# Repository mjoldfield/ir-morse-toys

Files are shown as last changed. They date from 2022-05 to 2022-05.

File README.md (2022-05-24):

# Games with Morse Code at 940nm

This repository contains designs for two detectors and two transmitters
for Morse Code signals, all working with 940nm infra-red light.

You can read more on [my website](https://mjoldfield.com/atelier/2022/01/ir-fun.html).

If you’re near Cambridge, UK you might enjoy the [geocache](https://www.geocaching.com/geocache/GC86BQY_to-the-birdhouse)
 for which they were designed.

## Building the firmware

There are three steps:

  1. Install a GNU toolchain. You can download this from
	 [ARM](https://developer.arm.com/Tools%20and%20Software/GNU%20Toolchain),
	 but it is often available as system package in e.g. Debian.

  1. Install [libopencm3](https://libopencm3.org):

		$ git submodule init
		
		$ git submodule upgrade

		$ make -C libopencm3

  1. Compile the firmware

		$ make -C tx-bluepill/firmware

		$ make -C tx-stm32l431/firmware

The libopencm3-rules.mk file contains a number of fake targets to flash the firmware.

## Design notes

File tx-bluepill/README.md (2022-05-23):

# A Bluepill STM32F103 based emitter



You can read more on [my website](https://mjoldfield.com/atelier/2022/01/ir-emitter-bp.html).

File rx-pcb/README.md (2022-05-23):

# A PCB based Detector



You can read more on [my website](https://mjoldfield.com/atelier/2022/01/rx-pcb.html).

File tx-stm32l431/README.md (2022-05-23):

# A STM32L431 based emitter



You can read more on [my website](https://mjoldfield.com/atelier/2022/01/ir-emitter-bb.html).

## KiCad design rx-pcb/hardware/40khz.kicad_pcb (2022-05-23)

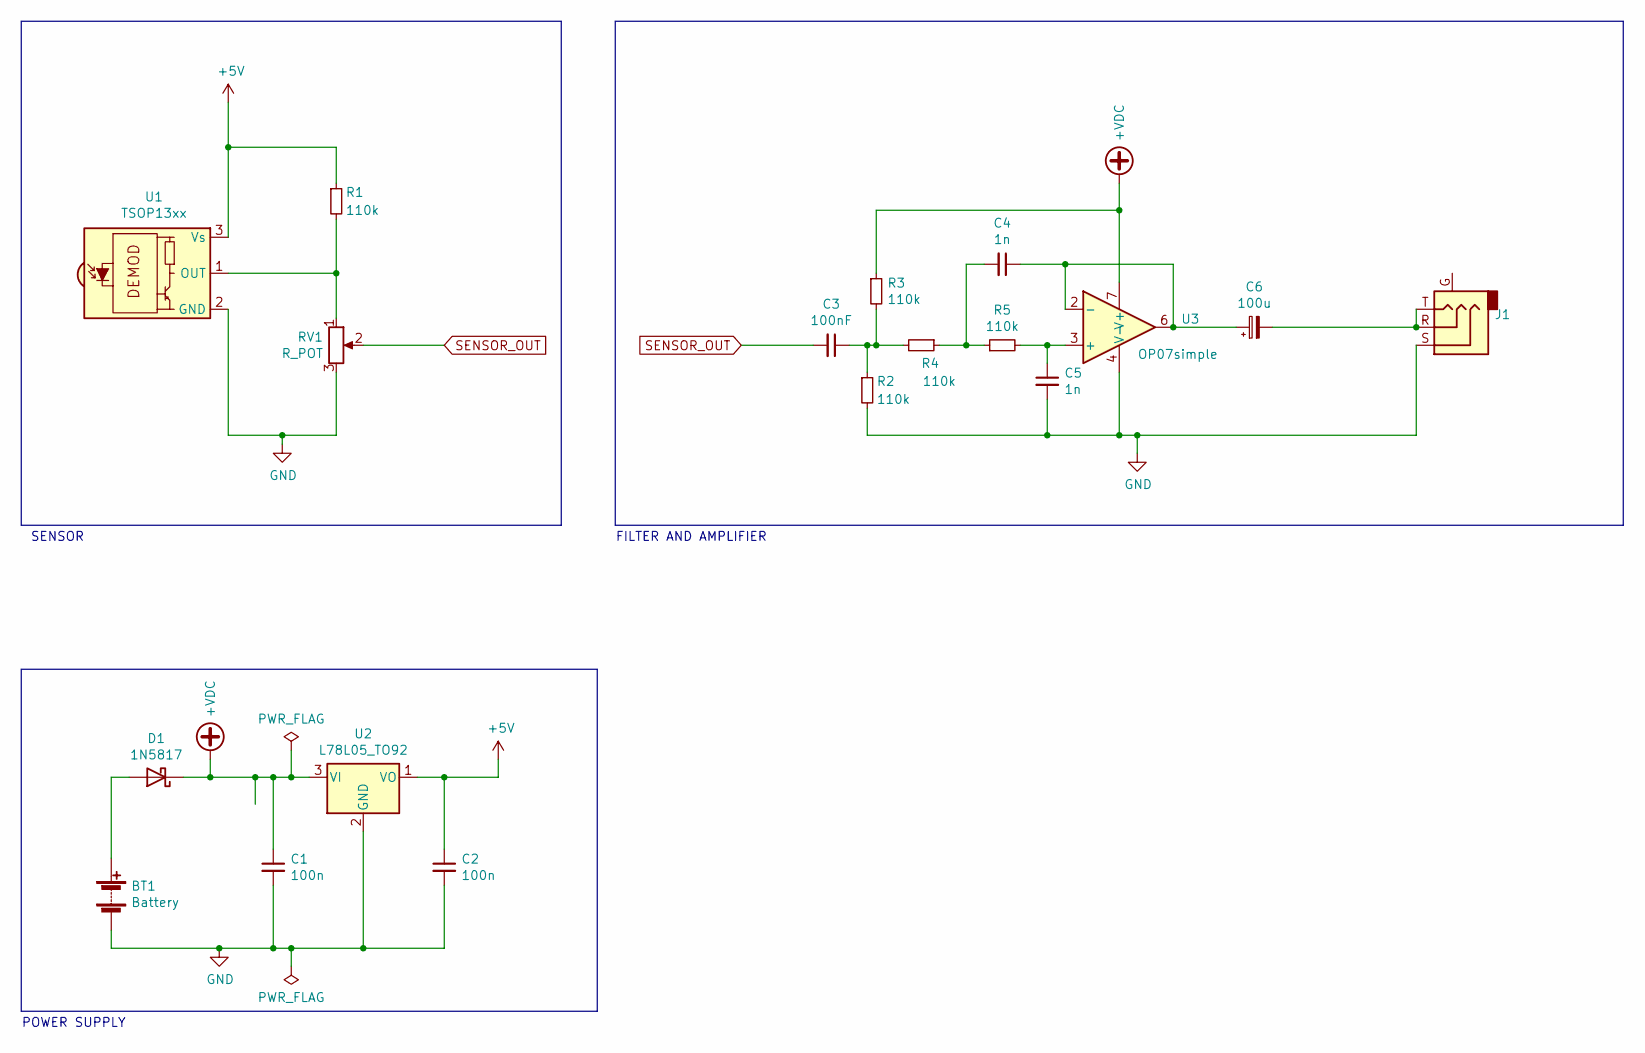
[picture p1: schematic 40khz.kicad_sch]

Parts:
BT1: Battery; Battery_Keystone_968
C1, C2: 100n; C_Disc_D10.0mm_W2.5mm_P5.00mm
C3: 100nF; C_Disc_D10.0mm_W2.5mm_P5.00mm
C4, C5: 1n; C_Rect_L10.0mm_W5.0mm_P5.00mm_P7.50mm
C6: 100u; CP_Radial_D6.3mm_P2.50mm
D1: 1N5817; D_DO-41_SOD81_P10.16mm_Horizontal
J1: AudioJack3_Ground; TruConnect_3.5mm_StereoSocket
R1, R2, R3, R4, R5: 110k; R_Axial_DIN0207_L6.3mm_D2.5mm_P10.16mm_Horizontal
RV1: R_POT; Potentiometer_Piher_PC-16_Single_Horizontal
U1: TSOP13xx; Vishay_MINIMOLD-3Pin
U2: L78L05_TO92; TO-92_Inline
U3: OP07simple; DIP-8_W7.62mm_Socket

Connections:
+5V: C2.1, R1.1, U1.3 (Vs), U2.1 (VO)
+VDC: C1.1, D1.1 (K), R3.1, U2.3 (VI), U3.7 (V+)
GND: BT1.2 (-), C1.2, C2.2, C5.2, J1.S, R2.2, RV1.3, U1.2 (GND), U2.2 (GND), U3.4 (V-)
unnamed: BT1.1 (+), D1.2 (A)
unnamed: C3.1, R2.1, R3.2, R4.2
unnamed: C4.1, C6.1, U3.2 (-), U3.6
unnamed: C4.2, R4.1, R5.1
unnamed: C5.1, R5.2, U3.3 (+)
unnamed: C6.2, J1.R, J1.T
unnamed: R1.2, RV1.1, U1.1 (OUT)
SENSOR_OUT: C3.2, RV1.2

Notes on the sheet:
SENSOR
POWER SUPPLY
FILTER AND AMPLIFIER

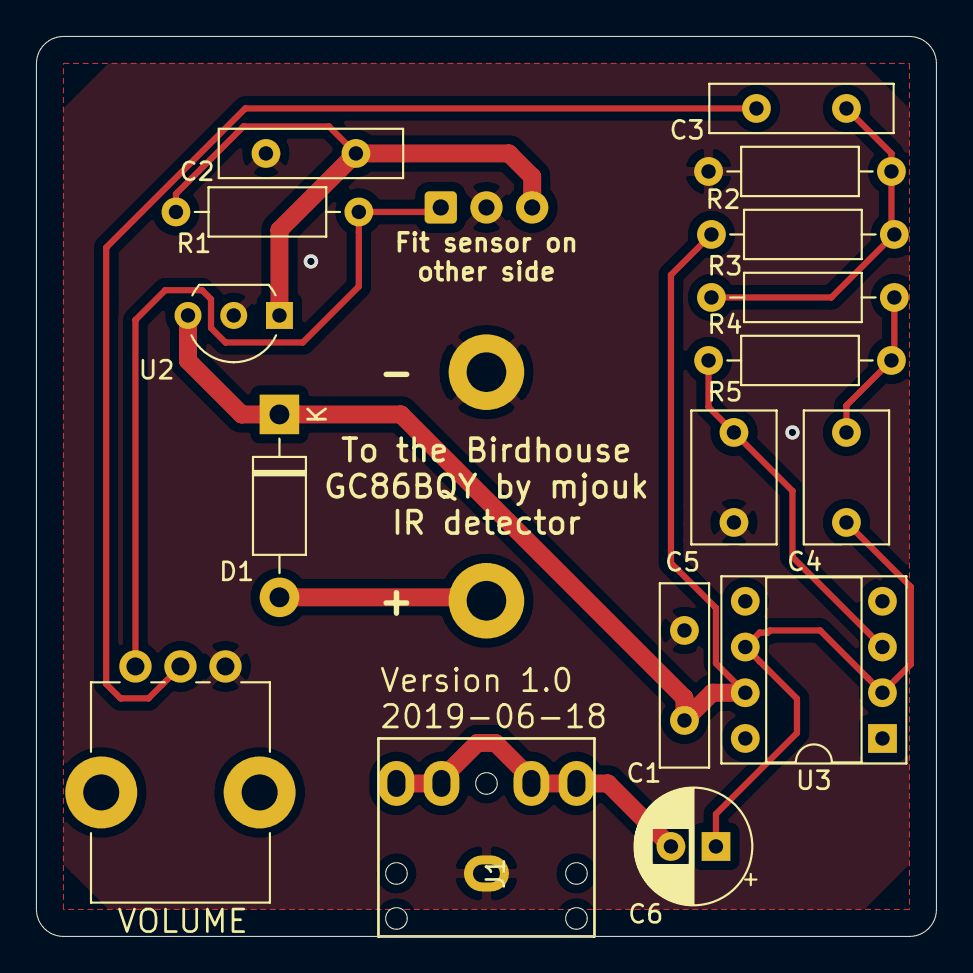
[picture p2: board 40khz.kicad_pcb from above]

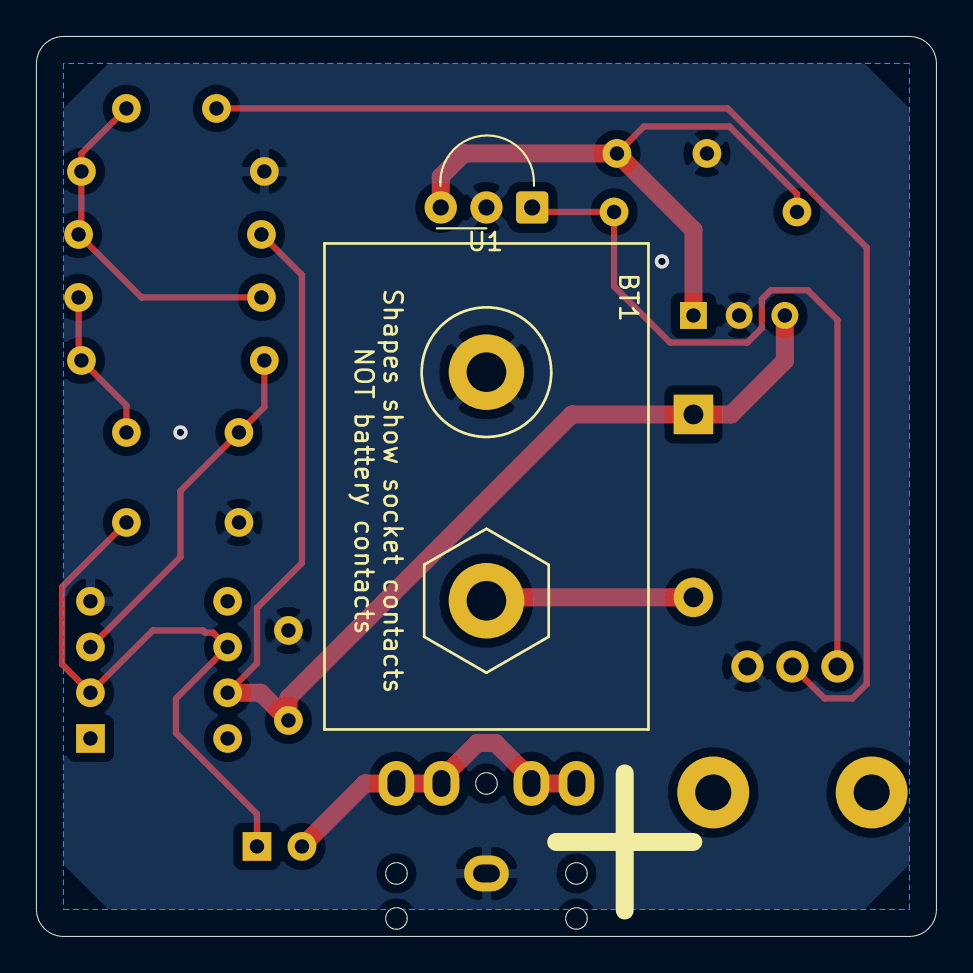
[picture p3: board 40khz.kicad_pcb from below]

Board: 2 copper layers, 50.0 x 50.0 mm, 18 parts (2 on the bottom side), 11 nets.

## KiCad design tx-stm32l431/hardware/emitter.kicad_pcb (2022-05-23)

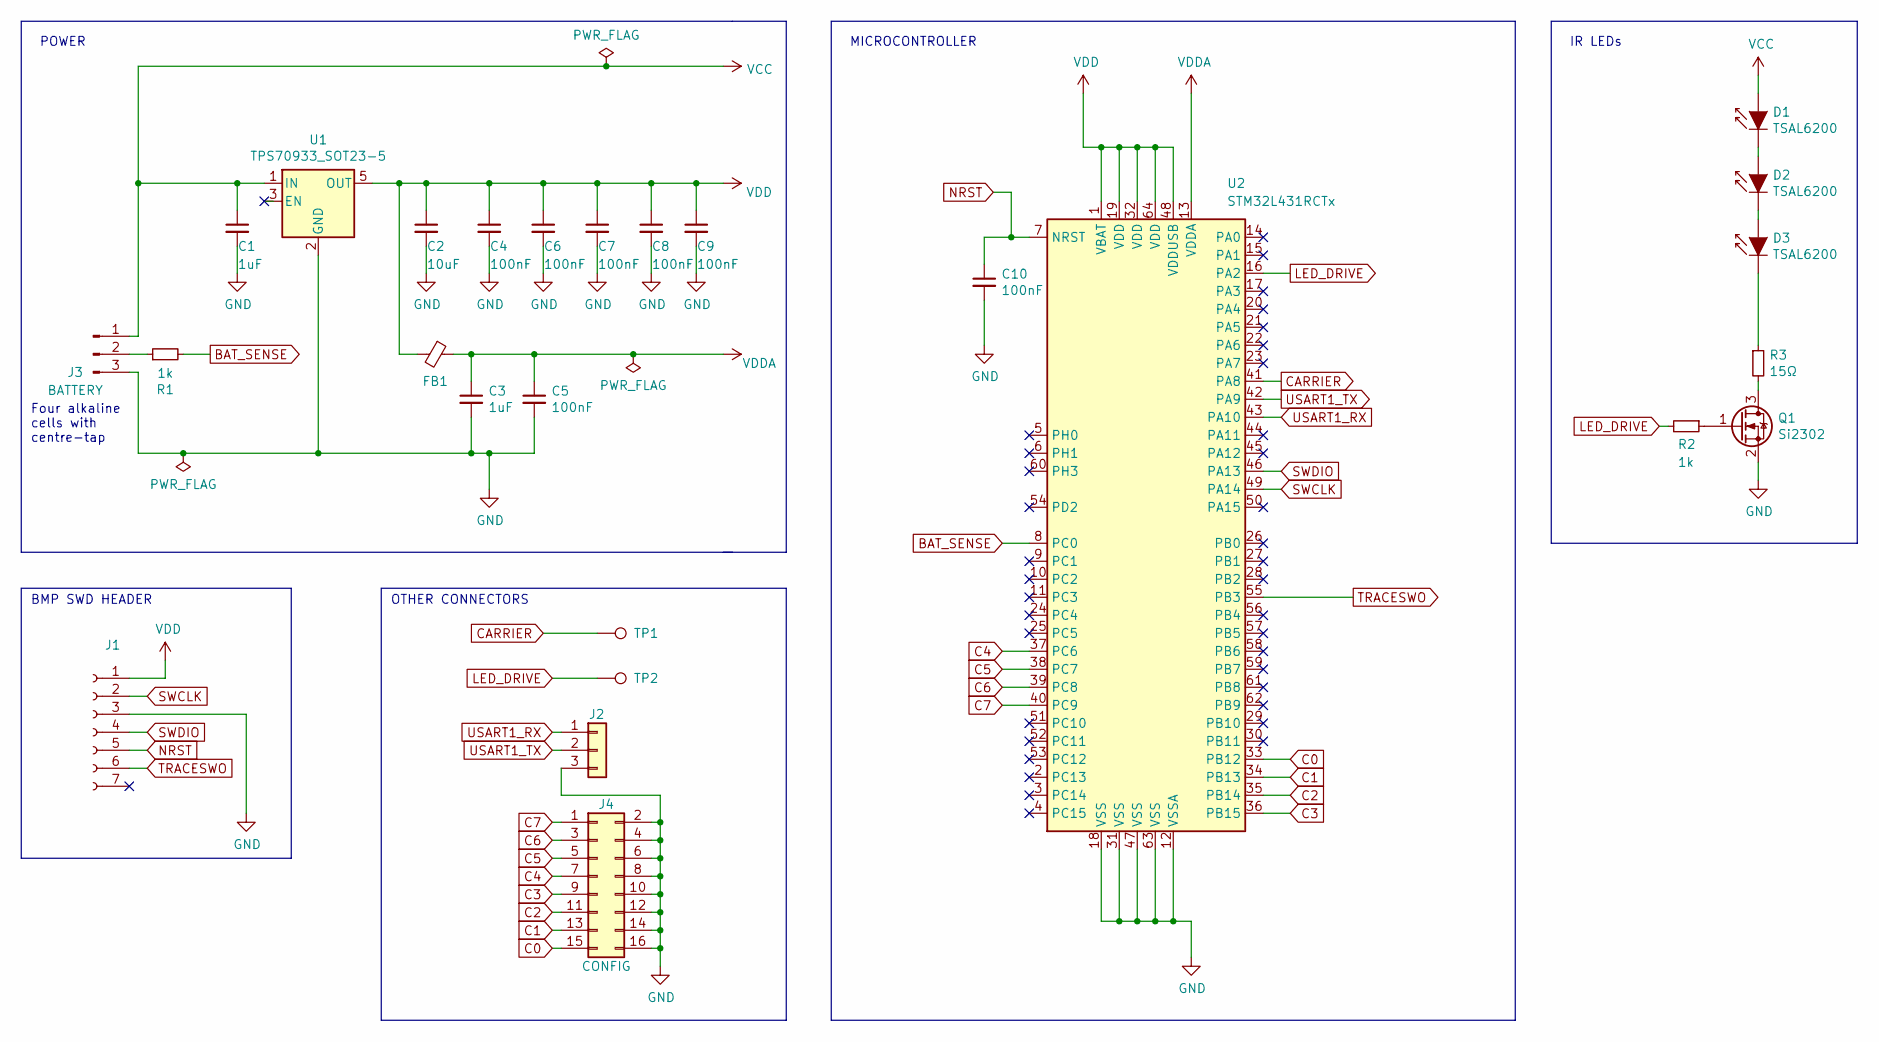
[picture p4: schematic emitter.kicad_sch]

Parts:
C1, C3: 1uF; C_0603_1608Metric_Pad1.05x0.95mm_HandSolder
C2: 10uF; C_0603_1608Metric_Pad1.05x0.95mm_HandSolder
C4, C5, C6, C7, C8, C9, C10: 100nF; C_0603_1608Metric_Pad1.05x0.95mm_HandSolder
D1, D2, D3: TSAL6200; LED_D5.0mm_Horizontal_O1.27mm_Z3.0mm_IRBlack
FB1: Ferrite_Bead_Small; L_0603_1608Metric_Pad1.05x0.95mm_HandSolder
J1: Conn_01x07_Female; PinSocket_1x07_P2.54mm_Vertical
J2: Conn_01x03; PinSocket_1x03_P2.54mm_Vertical
J3: BATTERY; PinHeader_1x03_P2.54mm_Vertical
J4: CONFIG; PinHeader_2x08_P2.54mm_Vertical
Q1: Si2302; SOT-23
R1, R2: 1k; R_0603_1608Metric_Pad1.05x0.95mm_HandSolder
R3: 15Ω; R_0603_1608Metric_Pad1.05x0.95mm_HandSolder
TP1, TP2: TestPoint; TestPoint_Loop_D2.60mm_Drill1.4mm_Beaded
U1: TPS70933_SOT23-5; SOT-23-5
U2: STM32L431RCTx; LQFP-64_10x10mm_P0.5mm

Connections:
BAT_SENSE: R1.2, U2.8 (PC0)
C0: J4.15, U2.33 (PB12)
C1: J4.13, U2.34 (PB13)
C2: J4.11, U2.35 (PB14)
C3: J4.9, U2.36 (PB15)
C4: J4.7, U2.37 (PC6)
C5: J4.5, U2.38 (PC7)
C6: J4.3, U2.39 (PC8)
C7: J4.1, U2.40 (PC9)
CARRIER: TP1.1, U2.41 (PA8)
GND: C1.2, C2.2, C3.2, C4.2, C5.2, C6.2, C7.2, C8.2, C9.2, C10.2, J1.3, J2.3, J3.3, J4.2, J4.4, J4.6, J4.8, J4.10, J4.12, J4.14, J4.16, Q1.2 (S), U1.2 (GND), U2.12 (VSSA), U2.18 (VSS), U2.31 (VSS), U2.47 (VSS), U2.63 (VSS)
LED_DRIVE: R2.2, TP2.1, U2.16 (PA2)
NRST: C10.1, J1.5, U2.7 (NRST)
unnamed: D1.1 (K), D2.2 (A)
unnamed: D2.1 (K), D3.2 (A)
unnamed: D3.1 (K), R3.1
unnamed: J3.2, R1.1
unnamed: Q1.1 (G), R2.1
unnamed: Q1.3 (D), R3.2
SWCLK: J1.2, U2.49 (PA14)
SWDIO: J1.4, U2.46 (PA13)
TRACESWO: J1.6, U2.55 (PB3)
USART1_RX: J2.1, U2.43 (PA10)
USART1_TX: J2.2, U2.42 (PA9)
VCC: C1.1, D1.2 (A), J3.1, U1.1 (IN)
VDD: C2.1, C4.1, C6.1, C7.1, C8.1, C9.1, FB1.2, J1.1, U1.5 (OUT), U2.1 (VBAT), U2.19 (VDD), U2.32 (VDD), U2.48 (VDDUSB), U2.64 (VDD)
VDDA: C3.1, C5.1, FB1.1, U2.13 (VDDA)

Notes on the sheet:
BMP SWD HEADER
IR LEDs
MICROCONTROLLER
OTHER CONNECTORS
POWER
Four alkaline cells with centre-tap

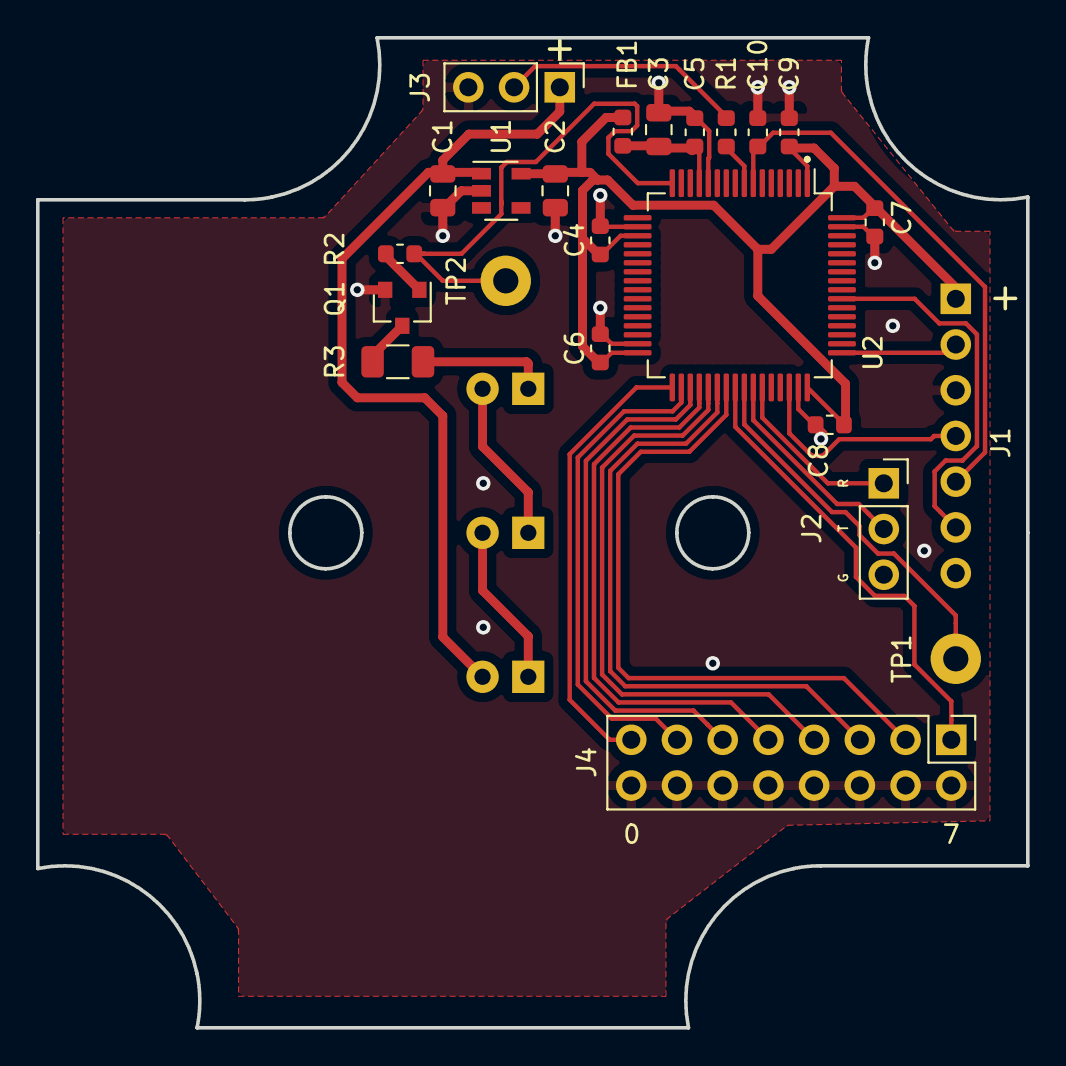
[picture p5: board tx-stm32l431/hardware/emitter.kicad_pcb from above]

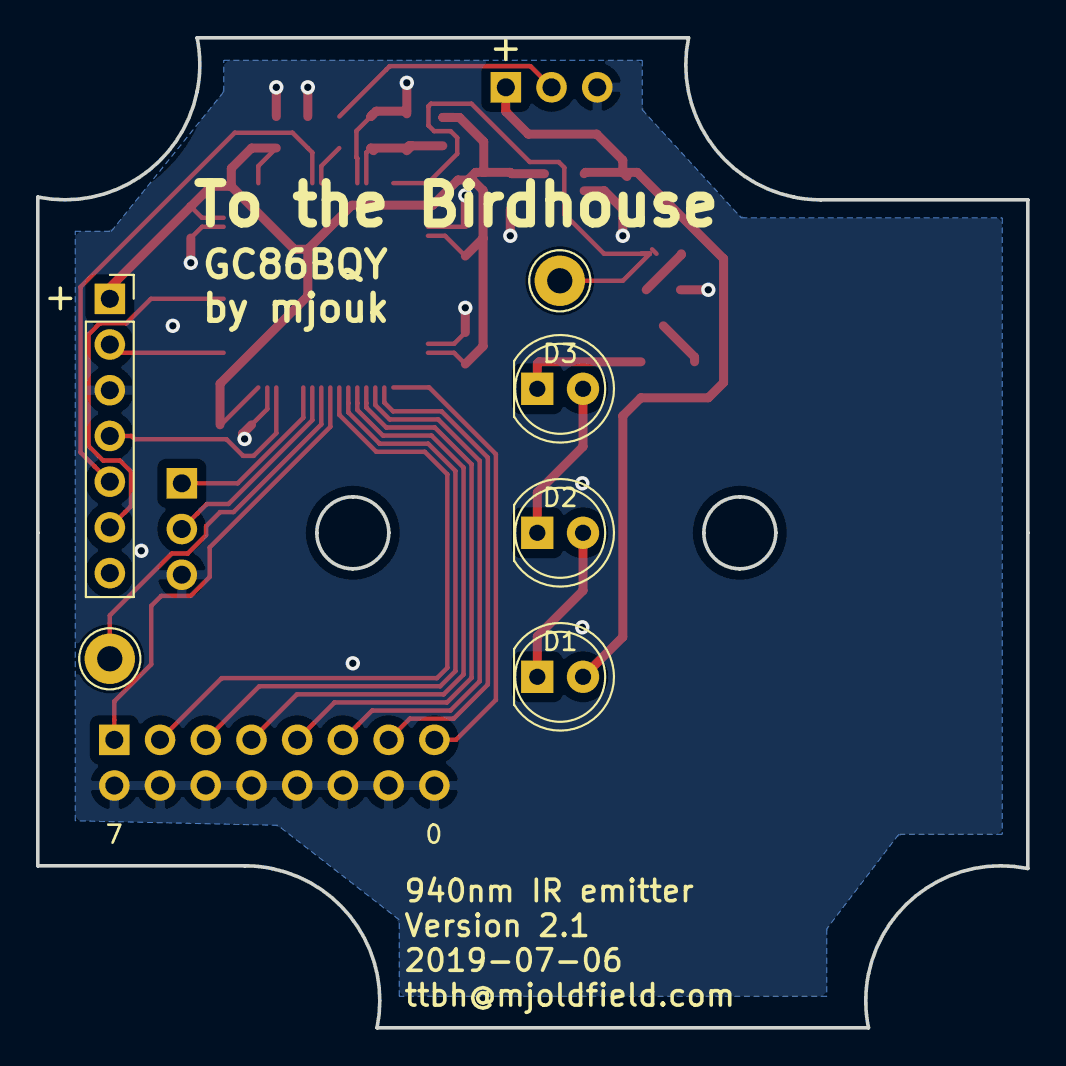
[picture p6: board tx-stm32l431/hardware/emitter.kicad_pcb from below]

Board: 2 copper layers, 55.0 x 55.0 mm, 26 parts (6 on the bottom side), 27 nets.

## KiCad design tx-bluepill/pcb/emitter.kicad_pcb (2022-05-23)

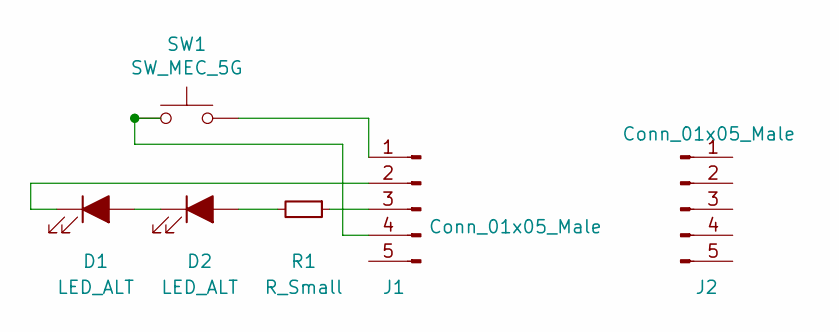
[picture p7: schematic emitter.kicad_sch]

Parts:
D1, D2: LED_ALT; LED_D5.0mm
J1, J2: Conn_01x05_Male; PinHeader_1x05_P2.54mm_Vertical
R1: R_Small; R_Axial_DIN0204_L3.6mm_D1.6mm_P5.08mm_Horizontal
SW1: SW_MEC_5G; SW_TH_Tactile_Omron_B3F-10xx

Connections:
unnamed: D1.1 (K), J1.2
unnamed: D1.2 (A), D2.1 (K)
unnamed: D2.2 (A), R1.2
unnamed: J1.1, SW1.3 (B), SW1.4 (B)
unnamed: J1.3, R1.1
unnamed: J1.4, SW1.1 (A), SW1.2 (A)

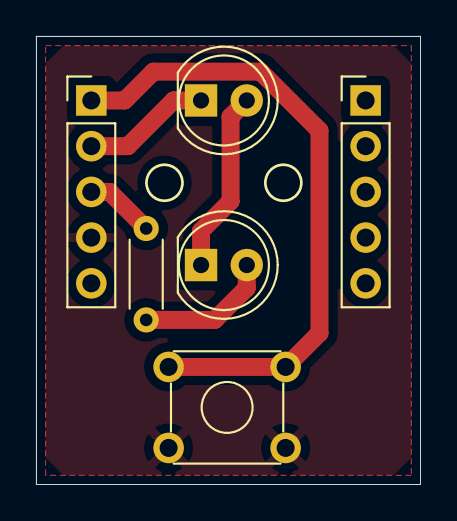
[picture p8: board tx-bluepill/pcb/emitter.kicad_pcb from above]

Board: 2 copper layers, 21.3 x 24.9 mm, 6 parts (0 on the bottom side), 6 nets.

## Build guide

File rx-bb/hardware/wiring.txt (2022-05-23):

Wire links

W1  J30  -
W2  H28 H25
W3  E2  F2

U1  A2 A3 A4

U2  F21 to E18

R1  C4   +

R2  B2  B4
R3  I12  -
R4  F12  +
R5  G12 G19

D1  D3  D4

C1  F4  H12

C2  B19 F25

VR1 J2 J4 J6

J1  F28 G28 H30 I28 J28

W4  E3  -
W5  F6  -
W6  G18 -
W7  D20 +
W8  F20 D19

B1

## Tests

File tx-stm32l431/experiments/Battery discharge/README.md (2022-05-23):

# Battery discharging

This directory contains data which shows how the battery
discharges when running the emitter when the duty-cycle
of the LED is increased as the battery voltage drops.

## Key results

  - On full-power AAA cells last about 10 hours;

  - D cells last about 12 times as long as AAA cells;

  - Running at 30% of power quadruples the lifetime.

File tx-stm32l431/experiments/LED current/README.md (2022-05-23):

# LED characterization

Currrent/Voltage plots for three and four LEDs in series.

The four LED string is more efficient at higher voltages but there's
not enough current when the batteries run down.  So, use three LEDs
and accept the wasted power at high voltages.

For an applied voltage in the range 4.0--6.5V (which covers the range
the battery will supply) the current is accurately modelled by:

	(I / mA) = 55.86 (V / V) - 200.58

Equivalently,

	(V / V) = 17.9 (I / A) + 3.59

Given that the current limiting resistor had a value of 15Ω this
suggests that the LED behaves as a voltage drop of 1.2V in series with
a 1Ω resistor.

# Model generation

The short Haskell program mkModel.hs generates C source and header files
to embed this model in firmware.

test.c is a simple program to test the model.

You can build them thus:

	stack runghc main.hs

	gcc -Wall -std=c99 -pedantic test.c ledcurve.c -o test

	./test

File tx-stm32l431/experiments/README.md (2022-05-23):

# Empirical tests

These directories contain the results of experiments
which characterized the performance of the emitter.
Documentation is poor.

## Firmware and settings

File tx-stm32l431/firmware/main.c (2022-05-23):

/* ex https://github.com/libopencm3/libopencm3-miniblink/blob/master/template_stm32.c */

#include <stddef.h>

#include <libopencm3/stm32/rcc.h>
#include <libopencm3/stm32/timer.h>
#include <libopencm3/stm32/gpio.h>
#include <libopencm3/stm32/adc.h>
#include <libopencm3/cm3/nvic.h>
#include <libopencm3/stm32/pwr.h>
#include <libopencm3/stm32/iwdg.h>
#include <libopencm3/stm32/flash.h>

#include "morseout.h"
#include "ledcurve.h"

typedef enum _gpio_pin_kind { GPIO_in, GPIO_out, GPIO_alt } gpio_pin_kind;

static const uint8_t gpio_out_set_hi  = 1;
static const uint8_t gpio_out_set_lo  = 2;

typedef struct _GPIOPin {
  uint16_t      pin;
  uint32_t      port;
  gpio_pin_kind kind;
  uint8_t       extra;
} GPIOPin;

// System clock
// 200kHz - 55.8uA, 400kHz - 68.5uA
static const uint32_t master_clk = RCC_CR_MSIRANGE_800KHZ;
static const uint32_t master_f   = 800000L; 

// carr   - 40kHz IR carrier clock
static const uint32_t              carr_freq       = 40000;
static const uint32_t              carr_timer      = TIM15;
static const uint32_t              carr_prescale   = 1;
static const uint32_t              carr_period     = master_f / (carr_freq * carr_prescale);


static const GPIOPin               leds_out = { GPIO2, GPIOA, GPIO_alt, GPIO_AF14 };

// tone_  - 800Hz Morse tone clock
static const uint32_t              tone_freq      = 800;
static const uint32_t              tone_timer     = TIM1;
static const uint32_t              tone_prescale  = 1;
static const uint32_t              tone_period    = master_f / (tone_freq * tone_prescale);

static const GPIOPin               carr_out = { GPIO8, GPIOA, GPIO_alt, GPIO_AF0 };   // MCO

// number of pulses in each burst of carrier, which lasts half the
// period of the tone
static const uint32_t              carr_pulses    = (carr_freq / tone_freq) >> 1;
// select the right master timer to get our trigger from
static const uint8_t               carr_trig_src  = TIM_SMCR_TS_ITR0;

//
// data - call after each symbol so 1,3,7,..  dit times
// 
// NB if this changes from TIM2 then references in the code below
// will have to be changed to match.
//
static const uint32_t              dit_time_ms    = 50;
static const uint32_t              data_timer     = TIM2;
static const uint32_t              data_prescale  = 5000;
static const uint32_t              data_period    = master_f * dit_time_ms /  (1000L * data_prescale);

// ADC for battery sense
static const uint32_t adc_batt      = ADC1;
static const uint32_t adc_batt_port = GPIOC;
static const uint16_t adc_batt_pin  = GPIO0;

static uint32_t v_batt = 0;

// Configuration data: read on boot, then fixed.
static uint32_t config = 0xffffffffL;
// LED power curve
static uint32_t led_curve_id = 0;

static const GPIOPin dbug_int      = { GPIO9, GPIOA, GPIO_out, gpio_out_set_lo };

// Config bits: read them, then set to output and drive LOW
// note the order is MSB first
static const GPIOPin configGPIOs[] = {
				         { GPIO9,   GPIOC, GPIO_in, GPIO_PUPD_PULLUP }
				       , { GPIO8,   GPIOC, GPIO_in, GPIO_PUPD_PULLUP }
				       , { GPIO7,   GPIOC, GPIO_in, GPIO_PUPD_PULLUP }
				       , { GPIO6,   GPIOC, GPIO_in, GPIO_PUPD_PULLUP }
				       , { GPIO15,  GPIOB, GPIO_in, GPIO_PUPD_PULLUP }
				       , { GPIO14,  GPIOB, GPIO_in, GPIO_PUPD_PULLUP }
				       , { GPIO13,  GPIOB, GPIO_in, GPIO_PUPD_PULLUP }
				       , { GPIO12,  GPIOB, GPIO_in, GPIO_PUPD_PULLUP }
					 , { 0, 0, 0, 0 }
};

// Morse code data
// 
// local mutable store for battery data
static const int morse_batt_status_n = 50;
static uint8_t morse_batt_status[50] = { 1,1,1,1,1, 3, 3,1,3,1,3, 3, 1,1,1,1,1, 0 };

static const uint8_t morse_message_pad_time = 20; // in dits

static uint32_t morse_msg_id = 0;


// how often should we update the battery voltage
// measured in complete passes through the message dictionary
//  - in practice this makes very little difference to current
// as configured below sampling takes ~1s, messages take ~30s
// so doing it every three messages means we read for ~1% of
// the time
static const uint32_t n_cycles_for_update = 3;
static volatile bool do_update = true;

//
// function prototypes
//
static void fatal_error(void);

static void init_std_timer(  uint32_t my_timer
			   , uint32_t my_prescale
			   , uint32_t my_period
			   , uint32_t my_period_off
			   );

static void init_gpio(GPIOPin const *my);
static void gpio_pulse_output(GPIOPin const *my);

static enum rcc_periph_clken clk_for_port(uint32_t port);
static enum rcc_periph_rst   rst_for_port(uint32_t port);

static void write_morse_number_check(volatile uint8_t *buff, uint32_t buffsize, uint32_t n);
static void write_morse_digit(volatile uint8_t *b, uint32_t d);

static void read_config(void);

static void reset_gpios(void);
static void reset_gpios_port(const uint32_t port, const uint16_t pins);

static void init_adc(const uint32_t adc
		     , const uint32_t port
		     , const uint16_t pins);


typedef uint8_t async_adc_state;
const async_adc_state async_adc_dormant = 0;
const async_adc_state async_adc_start   = 1;

static async_adc_state async_adc_convert(const   uint32_t adc
					 , const uint8_t  channel
					 , async_adc_state state
					 , uint32_t *result);

static void adc_set_regular_singleton(uint32_t adc, uint8_t channel);

static void set_duty_cycle(void);

static void init_clocks(void);

static void init_watchdog(void);
static void kick_watchdog(void);

static volatile bool int_enabled = false;

//
// here starteth the code
//
int main(void)
{
  rcc_periph_clock_enable(RCC_PWR);

  init_clocks();

  init_watchdog();

  // Read the config jumpers: messes with GPIO clock enables
  // so do this early.
  read_config();

  // Put all GPIOs in analog mode for power reduction
  reset_gpios();

  // explictly turn off LEDs
  {
    GPIOPin leds_tmp = leds_out;
    leds_tmp.kind  = GPIO_out;
    leds_tmp.extra = gpio_out_set_lo;
    init_gpio(&leds_tmp);
  }

  // 5 bits of message selection on 0--4
  // 3 bits of power curve on 5--7
  morse_msg_id = ((config >> 0) & 0x1f) ^ 0x1f;
  led_curve_id =  (config >> 5) & 0x07;

  ///////////////////////////////////////////////////////////////////////
  //
  // Carrier timer (40kHz) setup, taken from page 63 of AN4776
  // where it's called Timer 1. 
  //
  init_std_timer( carr_timer
		  , carr_prescale
		  , carr_period, carr_period >> 1
		  );

  timer_slave_set_trigger(carr_timer, carr_trig_src);
  timer_slave_set_mode(   carr_timer, TIM_SMCR_SMS_TM);

  timer_one_shot_mode(carr_timer);
  timer_set_repetition_counter(carr_timer, carr_pulses - 1);
  
  timer_enable_counter(carr_timer);

  ///////////////////////////////////////////////////////////////////////
  //
  // Tone timer setup (800Hz), taken from page 63 of AN4776
  // where it's called Timer 2
  //
  init_std_timer( tone_timer
		  , tone_prescale
		  , tone_period, tone_period >> 1
		  );

  timer_set_master_mode(tone_timer, TIM_CR2_MMS_UPDATE);
 
  timer_enable_counter(tone_timer);

  init_gpio(&leds_out);
  
  ///////////////////////////////////////////////////////////////////////
  // Status pins 
  //

  init_gpio(&carr_out);
  // put MCO on PA8
  RCC_CFGR |= (RCC_CFGR_MCO_SYSCLK << RCC_CFGR_MCO_SHIFT);
  //RCC_CFGR |= (RCC_CFGR_MCO_LSE << RCC_CFGR_MCO_SHIFT);

  ////////////////////////////////////////////////////////////////////////
  async_adc_state adc_state = async_adc_dormant;
  init_adc(adc_batt, adc_batt_port, adc_batt_pin);

  ///////////////////////////////////////////////////////////////////////
  //
  // Data timer setup: fire every dit time
  // -- enables interrupt so do this last.
  //
  init_std_timer( data_timer
		  , data_prescale
		  , data_period, 0
		  );

  timer_enable_irq(data_timer, TIM_DIER_UIE);
  nvic_enable_irq(NVIC_TIM2_IRQ);
  
  timer_enable_counter(data_timer);

  int_enabled = true;

  //
  // the main loop does very little beyond periodically reading the
  // battery voltage
  //
  // all the morse stuff is handled by hardware timers, updated by
  // the timer2 interrupt handler
  //
  while(1)
    {
      kick_watchdog();

      if (do_update) // flag set in ISR
	{
	  if (adc_state == async_adc_dormant)
	    adc_state = async_adc_start;

	  do_update = false;
	}

      if (adc_state != async_adc_dormant)
	{
	  const uint8_t adc_channel = 1;

	  uint32_t res = 99;
	  adc_state = async_adc_convert(adc_batt, adc_channel, adc_state, &res);

	  if (adc_state == async_adc_dormant)
	    {
	      v_batt = res;
	      write_morse_number_check(morse_batt_status,
				       morse_batt_status_n,
				       v_batt);
	      set_duty_cycle();
	    }
	}

      __asm__("wfi"); // sleep...

    }
}

void tim2_isr(void)
{
  // Assume clock speed 400kHz, so 2.5us per tick
  //
  // unoptimized code which calls libopencm3 takes time:
  //   150us to enable, 200us to disable
  // inlining direct register accesses takes
  //   105us to enable, 135us to disable
  //
  // All times are the measured time for which the dbug_pin
  // goes high.

  GPIO_BSRR(dbug_int.port) = dbug_int.pin;

  TIM2_SR &= ~TIM_SR_UIF;                                        // clear int flag in timer
  NVIC_ICPR(NVIC_TIM2_IRQ >> 5) = (1 << (NVIC_TIM2_IRQ & 0x1f)); // ... and in nvic
    

  static uint32_t phase = 0;
  static uint32_t msg_i = 0;
  const bool isMark = !(msg_i & 1);
    
  uint32_t tau = (phase == 0) ? morse_get_next_time(morse_msg_id + 1, &msg_i)
               : (phase == 1) ? morse_get_next_time(0,                &msg_i)
               :                morse_batt_status[msg_i++]
               ;

  if (tau == 0)
    {
      phase++;
      if (phase > 2)
	phase = 0;

      msg_i = 0;

      tau = morse_message_pad_time;

      static uint32_t i_cycles = 0;
      i_cycles++;
	  
      if (i_cycles == n_cycles_for_update)
	{
	  i_cycles = 0;
	  do_update = true;
	}
    }

    // work out how long next token should last
  const uint32_t period = data_period * tau - 1;
  if (isMark)
    {
      TIM_CR1(carr_timer) |= TIM_CR1_CEN; // enable timers
      TIM_CR1(tone_timer) |= TIM_CR1_CEN;
      
      TIM_ARR(data_timer) = period;
    }
  else
    {
      TIM_CR1(tone_timer) &= ~TIM_CR1_CEN; // disble timers
      TIM_CR1(carr_timer) &= ~TIM_CR1_CEN;
      
      TIM_ARR(data_timer) = period; 
      
      TIM_CNT(tone_timer) = 0;             // reset counts for next time
      TIM_CNT(carr_timer) = 0;
    }
  
  GPIO_BSRR(dbug_int.port) = dbug_int.pin << 16;
}

//
// Initialize a boring upward counting time with specified
// period and prescale value.
//
// If my_period_off is non-zero, also setup the OC1 output
// comparator.
//
static void init_std_timer(  uint32_t my_timer
			   , uint32_t my_prescale
			   , uint32_t my_period
			   , uint32_t my_period_off
			   )
{
  const enum rcc_periph_clken clk = clk_for_port(my_timer);
  const enum rcc_periph_rst   rst = rst_for_port(my_timer);
  
  rcc_periph_clock_enable(clk); 
  rcc_periph_reset_pulse(rst);

  timer_set_mode(my_timer
		 , TIM_CR1_CKD_CK_INT  // unity clock divider
		 , TIM_CR1_CMS_EDGE    // 
		 , TIM_CR1_DIR_UP      // count up
		 );

  timer_set_prescaler(my_timer, my_prescale - 1);
  timer_set_period(my_timer, my_period - 1);
  timer_set_counter(my_timer, 0);

  if (my_period_off != 0)
    {
      timer_set_oc_value(my_timer, TIM_OC1, my_period_off);
      timer_set_oc_mode( my_timer, TIM_OC1,TIM_OCM_PWM1);
      timer_set_oc_polarity_low(my_timer, TIM_OC1);

      timer_enable_oc_output(my_timer, TIM_OC1);
    }
      
  timer_enable_break_main_output(my_timer);
}

//
// Initialize a GPIO pin
//

static void init_gpio(GPIOPin const *my)
{
  enum rcc_periph_clken my_clk = clk_for_port(my->port);
  rcc_periph_clock_enable(my_clk);

  if      (my->kind == GPIO_in)
    {
      gpio_mode_setup(my->port, GPIO_MODE_INPUT, my->extra, my->pin);      
    }
  else if (my->kind == GPIO_out)
    {
      gpio_mode_setup(my->port, GPIO_MODE_OUTPUT, GPIO_PUPD_NONE, my->pin);

      if      (my->extra == gpio_out_set_hi)
	{
	  gpio_set(my->port, my->pin);
	}
      else if (my->extra == gpio_out_set_lo)
	{
	  gpio_clear(my->port, my->pin);
	}
      else
	{
	  fatal_error();
	}
    }
  else if (my->kind == GPIO_alt)
    {
      gpio_mode_setup(my->port, GPIO_MODE_AF, GPIO_PUPD_NONE, my->pin);
      gpio_set_af(my->port, my->extra, my->pin);
    }
  else
    {
      fatal_error();
    }
}

static void gpio_pulse_output(GPIOPin const *my)
{
  if (my->kind != GPIO_out)
    {
      fatal_error();
    }

  gpio_toggle(my->port, my->pin);
  gpio_toggle(my->port, my->pin);
}


//
// Initialize ADC
//
static void init_adc(const uint32_t adc
		     , const uint32_t port
		     , const uint16_t pins)
{
// ADC clock in AHB
  const enum rcc_periph_clken adc_clk  = clk_for_port(adc);
  rcc_periph_clock_enable(adc_clk);

  RCC_CCIPR   |= (3UL << 28);  // select system clock over PLLADC

  const enum rcc_periph_clken gpio_clk = clk_for_port(port);
  rcc_periph_clock_enable(gpio_clk);

  gpio_mode_setup(port, GPIO_MODE_ANALOG, GPIO_PUPD_NONE, pins);
}

//
// Do the next step in getting a number from the ADC
// - you'll need to thread the state through calls;
// - all bets are off if adc/channel change between calls
//
static async_adc_state async_adc_convert(const   uint32_t adc
					 , const uint8_t  channel
					 , const async_adc_state state
					 , uint32_t *result)
{
  bool finished = false;
  
  switch(state)
    {
    case 0:
      finished = true;

      break;
      
    case 1:
      ADC_CR(adc) &= ~ADC_CR_DEEPPWD;
      ADC_CR(adc) |=  ADC_CR_ADVREGEN;

      break;

    case 2:
      // adc_calibrate_async(adc); <- buggy
      ADC_CR(adc) |= ADC_CR_ADCAL;

      while(adc_is_calibrating(adc));

      adc_power_on(adc);

      adc_set_regular_singleton(adc, channel);
      
      adc_set_sample_time(adc, channel, ADC_SMPR_SMP_12DOT5CYC);

      ADC_CFGR2(adc) |= (3UL << 2) | 1UL; // 16x oversampling
      
      adc_start_conversion_regular(adc);

      break;
    
    case 3:
      
      while (!adc_eoc(adc))
	;

      uint32_t r = adc_read_regular(adc); // max is 16 * 4095

      // 3301 is 2^16 * 3300 / (16 * 4095)
      // 3300 is Vref is mV
      *result = (r * 3301UL) >> 16;

      adc_power_off(adc);

      ADC_CR(adc) |= ADC_CR_DEEPPWD;      
      
      finished = true;

      break;
    }

  const async_adc_state new_state = (finished)
                     ? async_adc_dormant
                     : state + 1;

  return new_state;
}

static void adc_set_regular_singleton(uint32_t adc, uint8_t channel)
{
  ADC_SQR1(adc) = ((uint32_t)channel) << ADC_SQR1_SQ1_SHIFT;
}


//
// look at the status of GPIO lines and write the config
// global byte
//
static void read_config(void)
{
  for(GPIOPin const *p = configGPIOs; p->pin != 0; p++)
    {
      const enum rcc_periph_clken clk = clk_for_port(p->port);

      rcc_periph_clock_enable(clk);

      // read the pin: might be tied low or floating
      init_gpio(p);
      const uint32_t dc = gpio_get(p->port, p->pin) == 0 ? 0 : 1;

      config <<= 1;
      config |=  dc;
    }
}

//
// Put all unused GPIOs into a sensible state.
// - in practice put all GPIOs there and reconfigure as needed
// - leave the SWD/JTAG stuff out so we can easily flash new
//   firmware
//
static void reset_gpios()
{
  reset_gpios_port(GPIOA, GPIO_ALL & !(GPIO13 | GPIO14));
  reset_gpios_port(GPIOB, GPIO_ALL & !(GPIO3));
  reset_gpios_port(GPIOC, GPIO_ALL);
  reset_gpios_port(GPIOD, GPIO2);
  reset_gpios_port(GPIOH, GPIO0 | GPIO1 | GPIO3);
}

static void reset_gpios_port(const uint32_t port, const uint16_t pins)
{
  const enum rcc_periph_clken clk = clk_for_port(port);
  
  rcc_periph_clock_enable(clk);

  //gpio_mode_setup(port, GPIO_MODE_ANALOG, GPIO_PUPD_NONE, pins);
  //gpio_mode_setup(port, GPIO_MODE_ANALOG, GPIO_PUPD_PULLDOWN, pins);
  gpio_mode_setup(port, GPIO_MODE_INPUT, GPIO_PUPD_PULLDOWN, pins);

  rcc_periph_clock_disable(clk);
}

//
// Given a buffer of buffsize write the Morse representation
// of n into it. Pad with leading zeros, and if the number's
// too big show the least significant digits only.
//
// Also add a check digit at the end so that the sum of all
// digits mod 10 is zero.
//
static void write_morse_number_check(volatile uint8_t *buff, uint32_t buffsize, uint32_t n)
{
  const uint32_t n_digits = buffsize / 10 - 1;

  uint8_t eoc = 3; // change to 7 for space after check

  uint32_t csum = 0;
  for(uint32_t i = 0; i < n_digits; i++)
    {
      const uint32_t d  = n % 10;
      n /= 10;

      csum += (10 - d);

      const uint32_t offset = 10 * (n_digits - i - 1);
      
      write_morse_digit(buff + offset, d);
      buff[offset + 9] = eoc;

      eoc = 3; // dah bettween digits
    }

  const uint32_t offset = 10 * n_digits;
  write_morse_digit(buff + offset, csum % 10);
  buff[offset + 9] = 0;
}

static void write_morse_digit(volatile uint8_t *b, uint32_t d)
{
  
  uint8_t  x1st = 1;
  uint8_t  x2nd = 3;
  uint32_t n1st = d;

  if (d >= 5)
    {
      x1st  = 3;
      x2nd  = 1;
      n1st -= 5;
    }

  for(uint32_t i = 0; i < 5; i++)
    {
      *b++ = (i < n1st) ? x1st : x2nd;
      *b++ = 1;
    }
}

//
// Convenience functions to return the clock and reset
// registers for various ports.
//
// It's a failing that we can't easily do something sensible
// if the port isn't handled by the switch.
//
static enum rcc_periph_clken clk_for_port(uint32_t port)
{
  switch(port)
    {
    case GPIOA:
      return RCC_GPIOA;
    case GPIOB:
      return RCC_GPIOB;
    case GPIOC:
      return RCC_GPIOC;
    case GPIOD:
      return RCC_GPIOD;
    case GPIOH:
      return RCC_GPIOH;
    case TIM1:
      return RCC_TIM1;
    case TIM2:
      return RCC_TIM2;
    case TIM15:
      return RCC_TIM15;
    case ADC1:
      return RCC_ADC;
    }
  return 0;
}

static enum rcc_periph_rst rst_for_port(uint32_t port)
{
  switch(port)
    {
    case TIM1:
      return RST_TIM1;
    case TIM2:
      return RST_TIM2;
    case TIM15:
      return RST_TIM15;
    }
  return 0;
}

static void init_clocks(void)
{
  // wait for MSI to be ready --- must do this before changing rate
  while(!(RCC_CR & RCC_CR_MSIRDY))
    ;
  
  // set MSI range
  {
    const uint32_t msi_range = master_clk;
    
    uint32_t rcc_cr = RCC_CR;    
    rcc_cr &= ~(RCC_CR_MSIRANGE_MASK << RCC_CR_MSIRANGE_SHIFT);
    rcc_cr |= msi_range << RCC_CR_MSIRANGE_SHIFT;
    rcc_cr |= RCC_CR_MSIRGSEL;
    RCC_CR = rcc_cr;
  }

  // Set MSI after reset range
  {
    const uint32_t msi_range = master_clk;
    
    uint32_t rcc_csr = RCC_CSR;    
    rcc_csr &= ~(RCC_CSR_MSIRANGE_MASK << RCC_CSR_MSIRANGE_SHIFT);
    rcc_csr |= msi_range << RCC_CSR_MSIRANGE_SHIFT;
    RCC_CSR = rcc_csr;
  }

  // Turn on LSI for IWDG
  RCC_CSR |= RCC_CSR_LSION;
  
  // wait for MSI to be ready
  while(!(RCC_CR & RCC_CR_MSIRDY))
    ;

  // wait for LSI to be ready
  while(!(RCC_CSR & RCC_CSR_LSIRDY))
    ;
  
  // Low power run mode
  PWR_CR1 |= PWR_CR1_LPR;
}

static void init_watchdog(void)  
{
  IWDG_KR = 0xcccc;
  IWDG_KR = 0x5555;
  IWDG_PR = IWDG_PR_DIV16;         // 16x prescale => 2s timeout

  while (IWDG_SR != 0) // wait until writes have finished
    ;

  //
  // The watchdog can be enabled by a bit in the option bytes
  // (FLASH_OPTR_IDWG):
  //    0 -> hardware mode (starts on boot)
  //    1 -> software mode (needs config above)
  //
  // Make sure that the bit's clear so we get start early.
  //

  const bool hw_wdg = (FLASH_OPTR & FLASH_OPTR_IDWG_SW) == 0;



  const uint32_t boot0_mask = 3 << 26;
  const uint32_t boot0_val  = 2 << 26;
  const bool boot_config_ok = (FLASH_OPTR & boot0_mask) == boot0_val;

  if (!hw_wdg || !boot_config_ok)
    {
      // the libopencm3 flash_program_option_bytes() call
      // does odd things (clearing the lowest two bits)
      // This code follows page 83 of the 32L4xxx ref. manual

      // wait until flash operations have finished
      while ((FLASH_SR & FLASH_SR_BSY) == FLASH_SR_BSY)
	;

      // write magic numbers to unlock flash
      FLASH_KEYR    = 0x45670123;
      FLASH_KEYR    = 0xCDEF89AB;
      
      FLASH_OPTKEYR = 0x08192A3B;
      FLASH_OPTKEYR = 0x4C5D6E7F;

      // clear relevant bit for watchdog
      FLASH_OPTR &= ~FLASH_OPTR_IDWG_SW;

      // tweak bits for boot
      FLASH_OPTR &= ~boot0_mask;
      FLASH_OPTR |=  boot0_val;

      // flag we're done
      FLASH_CR   |= FLASH_CR_OPTSTRT;

      // wait until done
      while ((FLASH_SR & FLASH_SR_BSY) == FLASH_SR_BSY)
	;
    }
}

static void set_duty_cycle(void)
{
  // at 800kHz have 20 clock ticks per 40kHz cycle, so sensible
  // off times are 10, 11, .. 19
  // 10 is full-power, 19 is minimal power

  // if we don't have a sane battery voltage, turn on full
  // power and bail early.

  uint32_t carr_period_off = 10;
  
  if (v_batt != 0)
    {
      const uint32_t dc = calc_duty_cycle(1, 10, led_curve_id, v_batt);
      carr_period_off = 20 - dc;
    }

  timer_set_oc_value(carr_timer, TIM_OC1, carr_period_off);
}


static void kick_watchdog(void)
{
  IWDG_KR = 0xaaaa;
}

static void fatal_error(void)
{
  while(1)
    ;
}

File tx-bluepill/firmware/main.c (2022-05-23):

/* ex https://github.com/libopencm3/libopencm3-miniblink/blob/master/template_stm32.c */

#include <libopencm3/stm32/rcc.h>
#include <libopencm3/stm32/gpio.h>

#include <libopencm3/cm3/nvic.h>     // for sys_tick_handler decl
#include <libopencm3/cm3/systick.h>

#include "morseout.h"

// Main IR LED on daughter board
// Use PB9 which is a 5V tolerant pin, and connect
// LEDs between +5V and PB9.
const uint32_t ir_led_pin   = GPIO9;
const uint32_t ir_led_port  = GPIOB;
const uint32_t ir_led_rcc   = RCC_GPIOB;

// Small green LED on Blue pill
const uint32_t grn_led_pin  = GPIO13;
const uint32_t grn_led_port = GPIOC;
const uint32_t grn_led_rcc  = RCC_GPIOC;
const uint32_t grn_led_ms   = 500;

// message select button
const uint32_t button_pin   = GPIO8;
const uint32_t button_port  = GPIOB;
const uint32_t button_rcc   = RCC_GPIOB;

// clock frequency: must match rcc_clock_setup line below
const uint32_t ahb_freq     = 72000000;

// times for Morse
const uint32_t carr_freq    =    40000;
const uint32_t subc_freq    =      800;
const uint32_t dit_t_ms     =       50;
const uint32_t space_t_ms   =      500;

// times for button handler
const uint32_t debounce_ms  =       25;
const uint32_t lng_prss_ms  =    10000;

// implicitly assumed by systick handler
const uint32_t tick_freq    =    carr_freq << 1;

// pre-calculate counts: factor of two because we do two transitions
// for each sub-carrier cycle
const uint32_t spc_cnt_limit  = ((subc_freq * space_t_ms)  / 1000) << 1;
const uint32_t dit_cnt_limit  = ((subc_freq * dit_t_ms)    / 1000) << 1;
const uint32_t debounce_limit = ((subc_freq * debounce_ms) / 1000) << 1;
const uint32_t lng_prss_limit = ((subc_freq * lng_prss_ms) / 1000) << 1;
const uint32_t grn_led_limit  = ((subc_freq * grn_led_ms)  / 1000) << 1;

static inline void real_sys_tick_handler(void);
static inline void read_button(bool *ret_pressed, uint32_t *ret_t_down);

int main(void)
{
  // Use libopencm3's clock routine: it's a bit involved
  // to do by hand.
  // this must match the ahb_freq defined above
  rcc_clock_setup_pll(&rcc_hse_configs[RCC_CLOCK_HSE8_72MHZ]);

  // IR LED
  rcc_periph_clock_enable(ir_led_rcc);
  gpio_set_mode(ir_led_port, GPIO_MODE_OUTPUT_2_MHZ,
		GPIO_CNF_OUTPUT_OPENDRAIN, ir_led_pin);

  // Green LED
  rcc_periph_clock_enable(grn_led_rcc);
  gpio_set_mode(grn_led_port, GPIO_MODE_OUTPUT_2_MHZ,
		GPIO_CNF_OUTPUT_PUSHPULL, grn_led_pin);

  // push button
  rcc_periph_clock_enable(button_rcc);
  gpio_set_mode(button_port, GPIO_MODE_INPUT,
		GPIO_CNF_INPUT_PULL_UPDOWN, button_pin);
  GPIO_ODR(button_port) |= button_pin; // enable pull-up

  // Use SysTick to generate 80kHz interruprs
  // See section 4.5 of PM0056: STM32F Cortex-M3 prog. manual
  // Macro names match libopencm3
  const uint32_t n_systicks = ahb_freq / tick_freq;

  STK_RVR  = n_systicks - 1;
  STK_CVR  = 0;
  STK_CSR |= STK_CSR_CLKSOURCE_AHB | STK_CSR_TICKINT | STK_CSR_ENABLE;

  // Now just sleep: everything of interest is in the sys_tick handler.
  while(1) {
    __asm__("wfi");
  }
}

void sys_tick_handler(void)
{
  // real handler can bail early, so wrap it here to be
  // sure we measure time properly

  //GPIO_BSRR(grn_led_port) = grn_led_pin << 16;
  real_sys_tick_handler();
  //GPIO_BSRR(grn_led_port) = grn_led_pin;
}

static inline void real_sys_tick_handler(void)
{
  // we get here every 1 / 80kHz = 12.5us
  // don't add code with varying runtime before setting
  // GPIO pin below, lest we introduce jitter

  static uint32_t state  = 0;
  static uint32_t msg_id = 0;

  // if all low order bits are clear then turn LED on...
  const bool      led_on = (state & 7) == 0;

  // .. which means clearing the relevant bit
  {
    const uint32_t mask = (led_on) ? (ir_led_pin << 16) : ir_led_pin;
    GPIO_BSRR(ir_led_port) = mask;
  }

  // modulate 40kHz carrier
  state ^= 1; // tick...

  // now modulate with 800Hz sub-carrier
  {
    const uint32_t tone_cnt_limit = carr_freq / subc_freq;
    static uint32_t tone_cnt = 0;
    tone_cnt++;
    if (tone_cnt < tone_cnt_limit)
      return;
    tone_cnt = 0;
  }
  state ^= 2;

  // we get here every 1 / 1600 =  625us
  {
    static uint32_t grn_led_cnt   = 0;
    static bool     grn_led_state = false;
    const  uint32_t cnt_limit     = grn_led_limit;
    if (grn_led_cnt++ == cnt_limit)
      {
	grn_led_cnt   = 0;
	grn_led_state = !grn_led_state;
	const uint32_t mask = (grn_led_state) ? (grn_led_pin << 16) : grn_led_pin;
	GPIO_BSRR(grn_led_port) = mask;
      }
  }

  static bool key_mode = false;

  bool     button_press;
  uint32_t t_button_down;
  read_button(&button_press, &t_button_down);

  if (t_button_down > lng_prss_limit)
    key_mode = true;

  if (key_mode)
    {
      state = (state & ~4) | (t_button_down == 0 ? 4 : 0);
      return;
    }

  // now add data modulation
  static uint32_t data_cnt_limit = spc_cnt_limit;
  static uint32_t data_cnt       = 0;

  static uint32_t msg_i = 0;

  if (button_press)
    {
      msg_id++;
      msg_i = 0;

      state |= 4;
      data_cnt       = 0;
      data_cnt_limit = spc_cnt_limit;
    }

  data_cnt++;
  if (data_cnt < data_cnt_limit)
    return;

  data_cnt = 0;

  // check msg_id lies within correct bounds
  const uint32_t msg_id_min  = 0;
  const uint32_t msg_id_max  = n_morse_messages;
  if (msg_id <  msg_id_min || msg_id >= msg_id_max)
    {
      msg_id = msg_id_min;
    }

  const uint32_t n_dits = morse_get_next_time(msg_id, &msg_i);
  if (n_dits == 0)
    {
      state |= 4;
      data_cnt_limit = spc_cnt_limit;
    }
  else
    {
      state ^= 4;
      data_cnt_limit = dit_cnt_limit * n_dits;
    }
}

static inline void read_button(bool *ret_pressed, uint32_t *ret_t_down)
{
  static uint32_t  t_down  = 0;
  static uint32_t debounce_timer = 0;

  const uint16_t b       = GPIO_IDR(button_port) & button_pin;
  const bool     is_down = (b == 0);

  bool pressed = false;

  if (is_down)
    {
      t_down++;

      if (debounce_timer == 0)
	{
	  pressed = true;
	}

      debounce_timer = debounce_limit;
    }
  else
    {
      t_down = 0;

      if (debounce_timer > 0)
	{
	  debounce_timer--;
	}
    }

  *ret_pressed = pressed;
  *ret_t_down  = t_down;
}
